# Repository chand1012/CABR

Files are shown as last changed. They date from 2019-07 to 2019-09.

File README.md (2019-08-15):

# CABR



The CABR (Pronounced KAY-BER) is a 3D printed Nerf Computerized Adaptive Bullpup Rifle for full length darts.

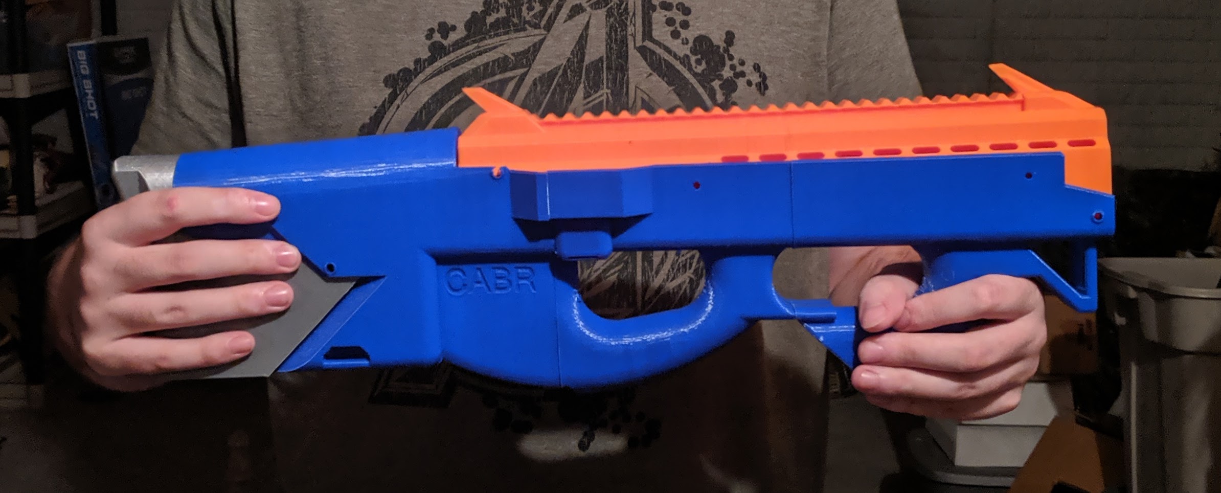
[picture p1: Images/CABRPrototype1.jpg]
CABR


# Features

- Simple design: only 8 printed parts for the blaster.
- Toolless access to the battery compartment, flywheel cage and barrel.
- Dual stage trigger.
- 41.5mm flywheel gap for the integral flywheel cage.
- Full length dart feed guide.
- FTW solenoid pusher.
- Full length picatinny top rail.
- Optional side picatinny rails.
- Integrated sling mounts.
- Computerized Semi, Burst, and Automatic modes.
- Battery buzzer for power detection.

# Required Parts

|Part |Quantity  |Description |
|---|---|---|
|Flywheel motors |2 |130 or 180 sized motors for flywheels [Purchase Link](https://outofdarts.com/collections/motors-2019/products/ood-kraken-motor) |
|Flywheels |2 |Flywheels [Purchase Link](https://outofdarts.com/collections/flywheels-cages/products/containment-crew-inferno-flywheels-pair) |
|FTW Solenoid |1 |FTW Solenoid for the pusher [Purchase Link](https://www.banggood.com/DC-12V-35mm-Long-Stroke-Push-Pull-Solenoid-Small-Electromagnetic-Electric-Magnet-p-1217063.html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) |
|Microswitch | 2 | For activating the motors and solenoid [Purchase Link](https://outofdarts.com/collections/electronics/products/21a-microswitch-button-clone) |
|Silicone insulated wire  | | Wiring [Purchase Link](https://www.amazon.com/BNTECHGO-Silicone-Flexible-Strands-Stranded/dp/B01C5CANVG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) |
|Heat set threaded inserts| 10 | To hold in screws (McMaster 94180A333 for 100) |
|Compression Spring | 1 | For trigger (McMaster 9657K56 for 12) |
|Torsion Spring | 1 | For magazine release (McMaster 9271K579 for 6) |
|M4x10 Socket head screw  | 1 | For securing the solenoid |
|M3x10 Socket head screws | 7 | |
|M3x25 Socket head screws | 2 | Used for flywheel switch and trigger |
|M3x35 Socket head screw  | 1 | For magazine release |
|M2 screws | 4 | For motors |
|2 1/2" x 3/16" Pins | 3 | For securing the battery and stock (McMaster 98330A125 for 10) |

# Additional Parts for circuitry

|Quantity|Ref Des |Desc |Part # |Manufacterer |Link |
|---|---|---|---|---|---|
|1 |U1 |Attiny85-20SU |Attiny85-20SU |Atmel |[Digikey](https://www.digikey.com/product-detail/en/microchip-technology/ATTINY85-20SU/ATTINY85-20SU-ND/735470) |
|1 |Q1 |Solenoid Transistor|PBSS4250X,115 |NXP |[Digikey](https://www.digikey.com/product-detail/en/nexperia-usa-inc/PBSS4250X115/1727-5750-1-ND/2697143) |
|1 |U2 |Voltage Reg |AZ1117CH-5.0TRG1DICT-ND|Diodes Inc |[Digikey](https://www.digikey.com/product-detail/en/diodes-incorporated/AZ1117CH-5.0TRG1/AZ1117CH-5.0TRG1DICT-ND/4505207)  |
|1 |D2 |Solenoid Diode |MMSD4148T3GOSTR-ND |ON Semi |[Digikey](https://www.digikey.com/product-detail/en/on-semiconductor/MMSD4148T3G/MMSD4148T3GOSCT-ND/1967161) |
|1 |C1 |Filter Cap |EMK212BBJ106MGHT |Taiyo Yuden |[Digikey](https://www.digikey.com/product-detail/en/taiyo-yuden/EMK212BBJ106MGHT/587-6311-1-ND/9949897) |
|1 |D1 |Status LED |LTST-C171GKT |Lite-On Inc |[Digikey](https://www.digikey.com/product-detail/en/lite-on-inc/LTST-C171GKT/160-1423-1-ND/386792) |
|4 |R1, R2, R4, R5|Resistor |RNCP0805FTD10K0 |Stackpole Electronics |[Digikey](https://www.digikey.com/product-detail/en/stackpole-electronics-inc/RNCP0805FTD10K0/RNCP0805FTD10K0CT-ND/2240601)|
|1 |R3 |Resistor |CRG0805F2K7 |TE Connectivity Passive Product|[Digikey](https://www.digikey.com/product-detail/en/te-connectivity-passive-product/CRG0805F2K7/A126359CT-ND/7603414) |
|1 |R6 |Resistor |RR1220P-102-D |Susumu |[Digikey](https://www.digikey.com/product-detail/en/susumu/RR1220P-102-D/RR12P1.0KDCT-ND/432830) |
|1 |C3 |MicroController Cap|CL21F104ZBCNNNC |Samsung Electro-Mechanics |[Digikey](https://www.digikey.com/product-detail/en/samsung-electro-mechanics/CL21F104ZBCNNNC/1276-1007-1-ND/3889093) |
|1 |C2 |Filter Cap |TMK212BBJ106KG-T |Taiyo Yuden |[Digikey](https://www.digikey.com/product-detail/en/taiyo-yuden/TMK212BBJ106KG-T/587-2985-1-ND/2714178) |
|1 |J2 |Fire Mode Switch |SS-13D16-VG 4 PA |C&K |[Digikey](https://www.digikey.com/product-detail/en/SS-13D16-VG+4+PA/CKN10371-ND/2747181) |

# Printing Parameters

Prototypes were printed using these parameters:

- PLA
- .3mm layer height
- .4mm nozzle
- 1.2mm vertical wall thickness
/- No supports (Except for the back of the reciever)

# Assembly

[Assembly guide on the repository wiki](https://github.com/chand1012/SABR/wiki/Assembly)

# Contributing

The project was designed using Fusion 360, under their hobbyist license.

# Attributions

This project uses the [FTW Solenoid by FlywheelTheWorld](https://www.thingiverse.com/thing:3518739) and the [FTW Solenoid Pusher Head by FlywheelTheWorld](https://www.thingiverse.com/thing:3307908).

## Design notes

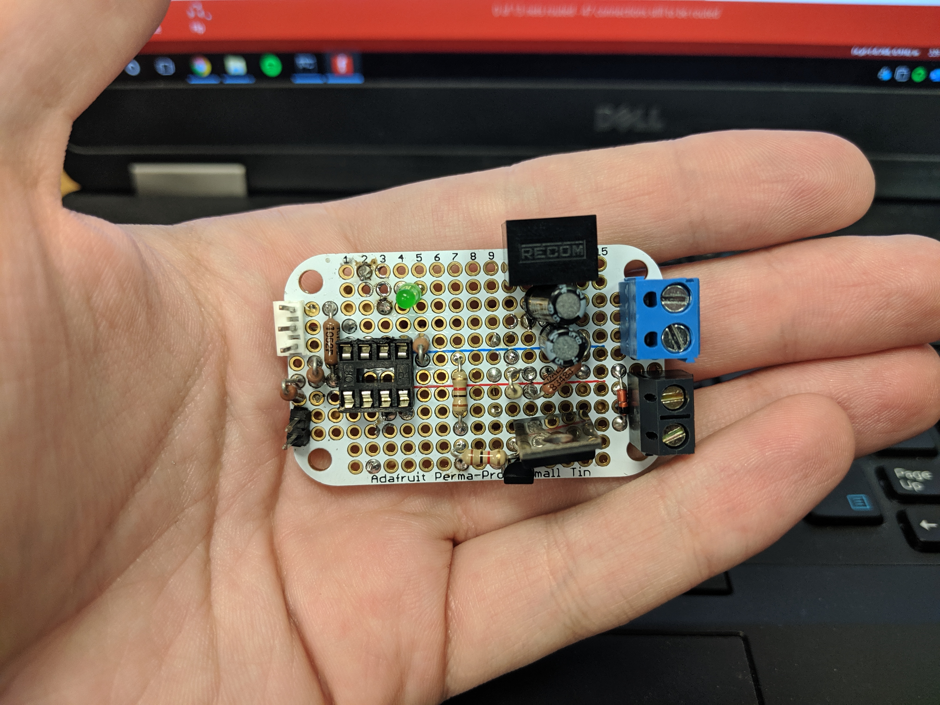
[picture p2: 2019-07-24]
ProtoTypeSchematic/Prototype (2).jpg

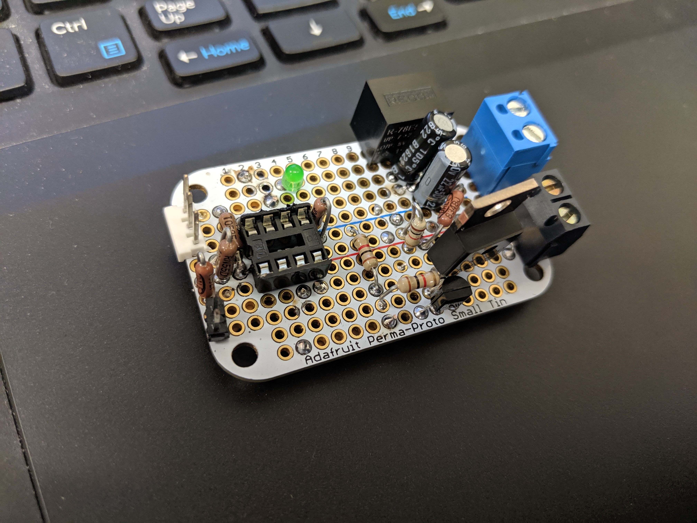
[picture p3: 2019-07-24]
ProtoTypeSchematic/Prototype (1).jpg

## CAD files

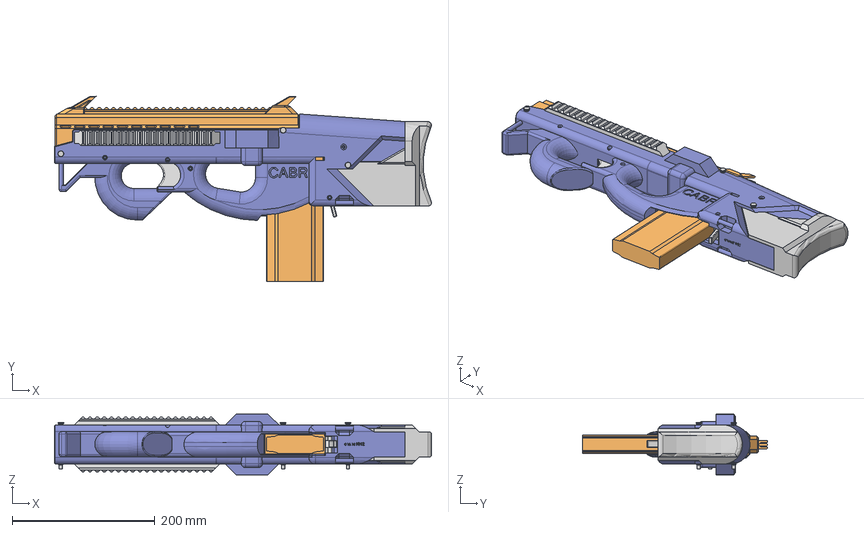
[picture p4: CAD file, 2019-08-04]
STEP/CABR.step
529.1 x 260.3 x 85.0 mm
Receiver
Trigger
FlywheelCage
NerfMagazine
Barrel
MagRelease
Frame Back Plate
Frame Plate
Magnet Body
C-Ring
pusher
98330A125 x 3
Stock
Rail x 2
180Motor x 2
Case x 2
NCTab x 2
ComTab x 2
NOTab x 2
Lid x 2
Button x 2
CC-Inferno x 2

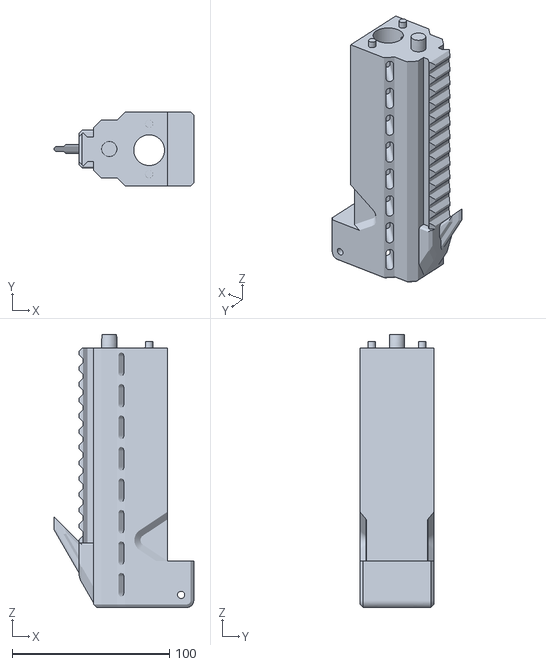
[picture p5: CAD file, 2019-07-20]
STL/Barrel Split/Barrel Front.stl
88.7 x 47.0 x 173.5

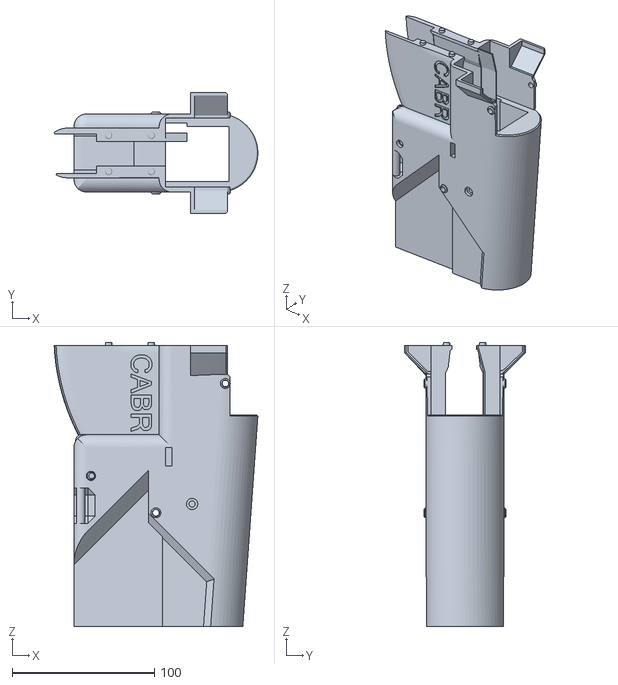
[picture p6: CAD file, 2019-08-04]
STL/Reciever Split/Reciever_Rear_CABR.stl
143.4 x 85.0 x 199.9

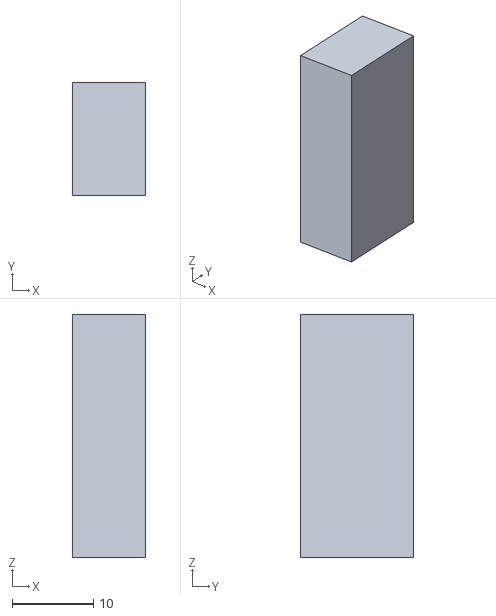
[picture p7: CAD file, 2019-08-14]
STL/SupportBlock.stl
9.00 x 14.0 x 30.0

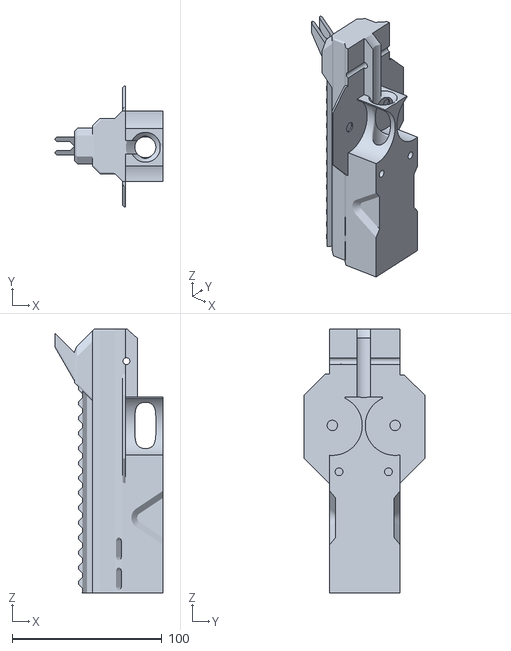
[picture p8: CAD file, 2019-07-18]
STL/Barrel Split/Barrel Rear.stl
72.0 x 80.6 x 176.5

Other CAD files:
STL/Reciever Split/Reciever_Rear_CABR_Nifty.stl

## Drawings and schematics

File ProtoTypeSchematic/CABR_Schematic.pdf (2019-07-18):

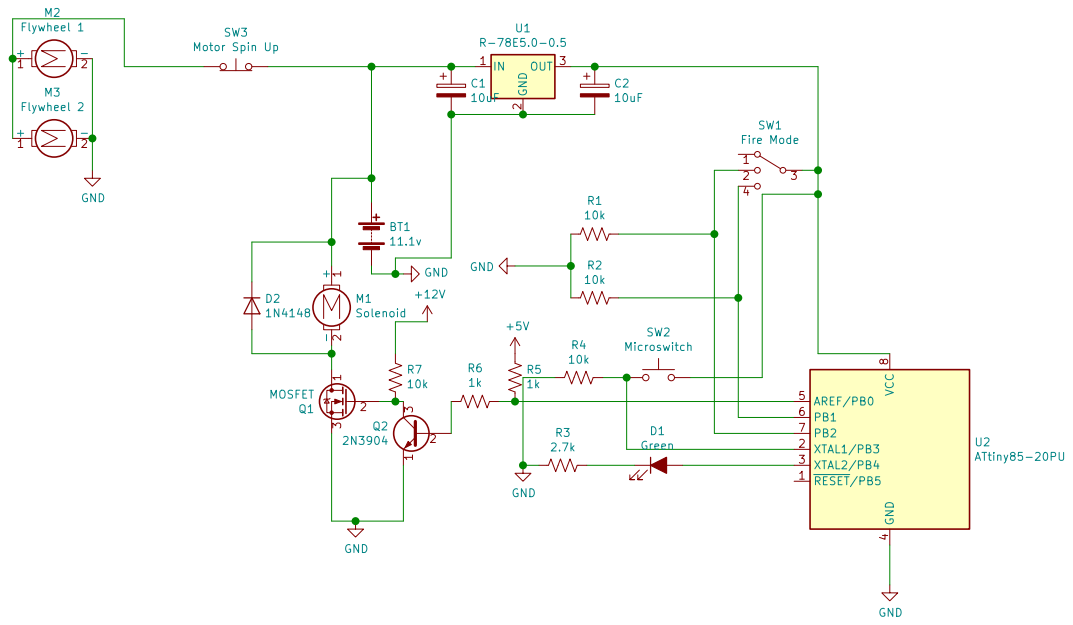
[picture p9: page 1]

3 Q1 MOSFET GND GND GND GND GND

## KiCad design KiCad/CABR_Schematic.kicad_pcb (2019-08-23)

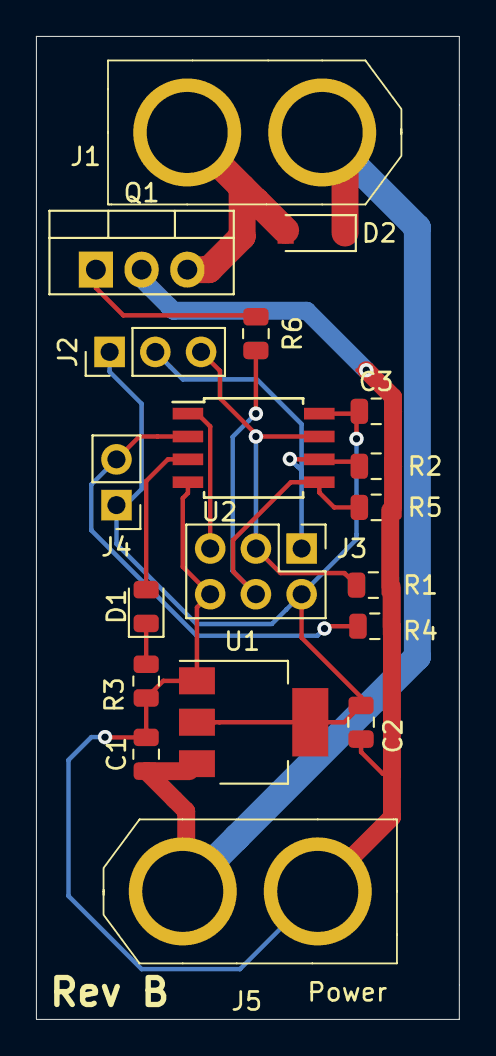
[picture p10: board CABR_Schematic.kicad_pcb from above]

Board: 2 copper layers, 23.5 x 54.6 mm, 19 parts (0 on the bottom side), 12 nets.

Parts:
C1, C2: 10uF; C_0805_2012Metric
C3: 0.1uF; C_0805_2012Metric
D1: Green; LED_0805_2012Metric
D2: MMSD4148T3G; D_SOD-123
J1, J5: XT60
J2: 0.1" Header; PinHeader_1x03_P2.54mm_Vertical
J3: Program Header; PinHeader_2x03_P2.54mm_Vertical
J4: MicroSwitch; PinHeader_1x02_P2.54mm_Vertical
Q1: FQP30N06L; TO-220-3_Vertical
R1, R2, R4, R5: 10k; R_0805_2012Metric
R3: 2.7k; R_0805_2012Metric
R6: 1k; R_0805_2012Metric
U1: AZ1117-5.0; SOT-223-3_TabPin2
U2: ATtiny85-20SU; SOIJ-8_5.3x5.3mm_P1.27mm

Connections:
GND: C1.2, C2.2, C3.2, J3.6, J5.2, Q1.2, R1.1, R2.2, R3.2, R4.2, R5.1, U1.1, U2.4
unnamed: C1.1, D2.1, J1.1, J5.1, U1.3
unnamed: C2.1, C3.1, J2.1, J3.2, J4.1, U1.2, U2.8
unnamed: D1.1, R3.1
unnamed: D1.2, U2.3
unnamed: D2.2, J1.2, Q1.3
unnamed: J2.2, J3.1, R2.1, U2.6
unnamed: J2.3, J3.3, R1.2, U2.7
unnamed: J3.4, R5.2, R6.1, U2.5
unnamed: J3.5, U2.1
unnamed: J4.2, R4.1, U2.2
unnamed: Q1.1, R6.2

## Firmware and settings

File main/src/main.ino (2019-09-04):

#define READY 4
#define TRIGGER 3
#define BURST 1
#define AUTO 2
#define MOSFET 0
#define AUTOMODE 2
#define BURSTMODE 1
#define SEMIMODE 0
#define EDELAY 50
#define SDELAY 100
#define ADELAY 175
#define BDELAY 75

unsigned int count;
byte mode;
byte firing;

void fire(int waittime) {
    digitalWrite(READY, LOW);
    digitalWrite(MOSFET, HIGH);
    delay(EDELAY);
    digitalWrite(MOSFET, LOW);
    delay(waittime);
    digitalWrite(READY, HIGH);
}

void setup() {
    pinMode(READY, OUTPUT);
    pinMode(MOSFET, OUTPUT);
    pinMode(TRIGGER, INPUT);
    pinMode(BURST, INPUT);
    pinMode(AUTO, INPUT);
    digitalWrite(READY, HIGH);
}

void loop() {
    if (digitalRead(BURST)) {
        mode = BURSTMODE;
    } else if (digitalRead(AUTO)) {
        mode = AUTOMODE;
    } else {
        mode = SEMIMODE;
    }
    
    firing = digitalRead(TRIGGER);
    if (firing) {
        switch (mode) {
        case SEMIMODE:
            if (count==0) {
                fire(SDELAY);
                count++;
            }
            break;
        case BURSTMODE:
            if (count <= 2) {
                fire(BDELAY);
                count++;
            }
            break;
        case AUTOMODE:
            if (count <= 22){
                fire(ADELAY);
                count++;
                break;
            }
        default:
            digitalWrite(MOSFET, LOW);
            break;
        }
    } else {
        count = 0;
    }
    
}

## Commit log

2019-07-15 added main arduino file and to gitignore
2019-07-16 finalized arduino code
2019-07-16 added schematic pdf
2019-07-16 Added CABR Back Reciever File
    [Reciever_Rear_CABR.stl]
2019-07-16 Added nifty parts reciever
    [Reciever_Rear_CABR_Nifty_Parts.stl]
2019-07-16 fixed non manifold issue
    [Reciever_Rear_CABR_Nifty_Parts.stl]
2019-07-16 removed SABR rear
    [Reciever_Rear.stl]
2019-07-18 moved some files around
    [Reciever_Rear_CABR.stl, Reciever_Rear_CABR_Nifty_Parts.stl, SABR.step]
2019-07-18 fixed rear barrel scaling
    [Barrel Rear.stl]
2019-07-18 fixed schematic
2019-07-18 Added fritzing board layout
    [CABR.fzz]
2019-07-18 fixed issues with transistor
    [CABR.fzz]
2019-07-19 updated the fritzing perfboard layout
    [CABR.fzz]
2019-07-19 more fritzing things
    [CABR.fzz]
2019-07-20 fixed issue with front barrel not fitting rear barrel
    [Barrel Front.stl]
2019-07-23 added non nifty reciever
    [Reciever_Rear_CABR.stl, Reciever_Rear_CABR_Nifty.stl]
2019-07-23 Added kicad files
    [CABR.fzz, CABR_Schematic.kicad_pcb, CABR_Schematic.sch]
2019-07-24 added prototype code for the board
2019-07-24 got PCB design
    [CABR_Schematic.sch]
2019-07-24 redid file structure
    [CABR.fzz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]
2019-07-24 Edited frizing prototype
    [CABR.fzz]
2019-07-24 added prototype photo
2019-07-25 fixed issues with prototype
    [CABR.fzz]
2019-07-25 updated PCB and gerber files
    [CABR_Schematic-B_Cu.gbr, CABR_Schematic-B_Mask.gbr, CABR_Schematic-B_Paste.gbr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]
2019-07-25 more pcb changes
    [CABR_Schematic.kicad_pcb]
2019-07-25 updated PCB again
    [CABR_Schematic-B_Cu.gbr, CABR_Schematic-B_Mask.gbr, CABR_Schematic-B_Paste.gbr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]
2019-07-25 added BOM to readme
2019-07-30 edited step file
    [CABR_Schematic-B_Cu.gbr, CABR_Schematic-B_Mask.gbr, CABR_Schematic-B_Paste.gbr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]
2019-07-30 Renamed to CABR
    [CABR.step]
2019-07-31 changed code?
    [CABR_Schematic-F_Fab.gbr]
2019-07-31 made changes for solenoid output
2019-07-31 modified delay times for solenoid
2019-08-04 added switch slot
    [CABR.step, Reciever_Rear_CABR.stl]
2019-08-06 added support block
    [SupportBlock.stl]
2019-08-14 updated prototype sketch
2019-08-14 updated block
    [SupportBlock.stl]
2019-08-20 fixed issue with boardfire
    [CABR_Schematic.kicad_pcb]
2019-08-21 updated design and fixed output pins
    [CABR_Schematic.kicad_pcb, CABR_Schematic.sch]
2019-08-21 more board updates
    [CABR_Schematic.kicad_pcb, CABR_Schematic.sch]
2019-08-21 more modifications
    [CABR_Schematic.kicad_pcb, CABR_Schematic.sch]
2019-08-22 more fixes
    [CABR_Schematic-B_Cu.gbr, CABR_Schematic-B_Mask.gbr, CABR_Schematic-B_Paste.gbr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]
2019-08-22 update schematic
    [CABR_Schematic.sch]
2019-08-22 more updates
    [CABR_Schematic.kicad_pcb, CABR_Schematic.sch]
